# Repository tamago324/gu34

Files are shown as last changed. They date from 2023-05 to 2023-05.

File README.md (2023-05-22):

# gu34

horizon プラグインを使ってボトムプレートとトッププレートを生成した

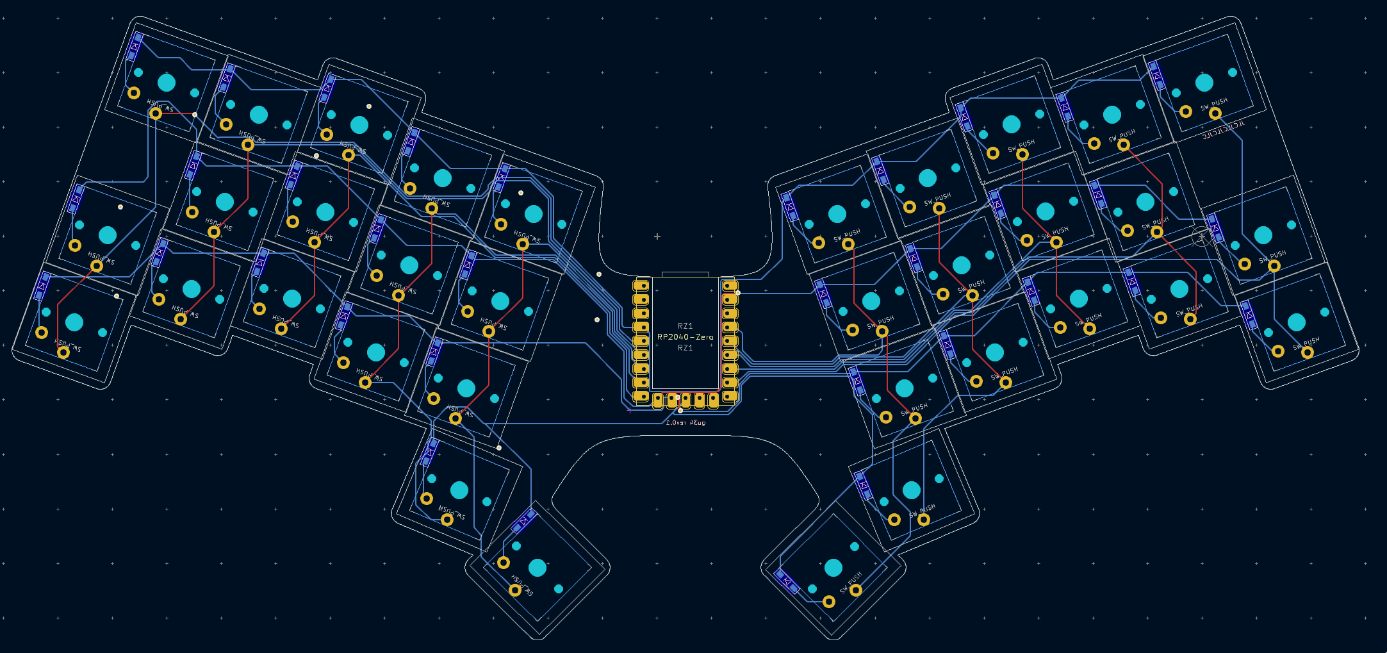
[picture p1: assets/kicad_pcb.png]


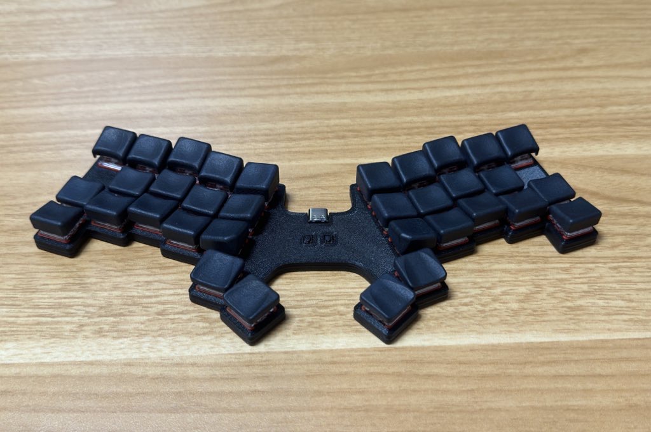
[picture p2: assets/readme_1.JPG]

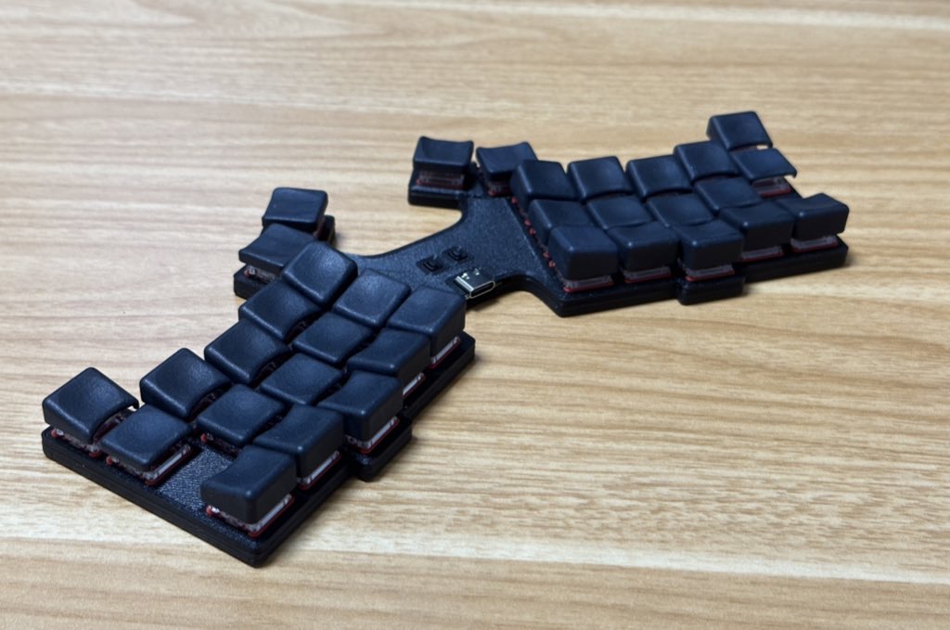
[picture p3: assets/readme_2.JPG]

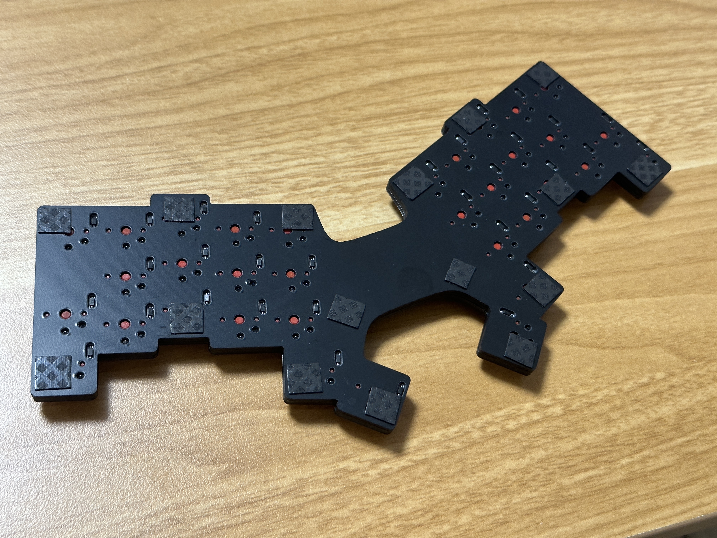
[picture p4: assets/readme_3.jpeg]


## LICENSE

<br />この 作品 は <a rel="license" href="http://creativecommons.org/licenses/by-nc/4.0/">クリエイティブ・コモンズ 表示 - 非営利 4.0 国際 ライセンス</a>の下に提供されています。

> 表示 — あなたは 適切なクレジットを表示し、ライセンスへのリンクを提供し、変更があったらその旨を示さなければなりません。これらは合理的であればどのような方法で行っても構いませんが、許諾者があなたやあなたの利用行為を支持していると示唆するような方法は除きます。
>
> 非営利 — あなたは営利目的でこの資料を利用してはなりません。

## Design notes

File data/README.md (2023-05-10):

# gu34

## 発注するためのデータの作り方

1. (horizon プラグイン)[https://github.com/skarrmann/horizon]を KiCAD に入れる
2. `revX` (`rev0.1` や `rev0.2` など) 内の `pcb/gu34.kicad_pcb` を開く
3. horizon プラグインを使って、発注するためのデータを作成する

## horizon プラグインの使い方

### もととなるKiCADのデータの作成方法

ボトムプレートとトッププレートを生成するためのデータはレイヤごとに作成されます

* `F.Adhesive` レイヤ：トッププレートの穴とEdge.Cuts
* `B.Adhesive` レイヤ：ボトムプレートの穴とEdge.Cuts

### horizon プラグインを使用して、ボトムプレートとトッププレートのデータを生成する

PCBエディタを開き、ツール > 外部プラグイン > Horizon Board Productor を実行する。

正しく実行できた場合、`data/` ディレクトリに `temp` と `gerbers` が生成される。

`temp` は KiCAD プロジェクトで、`gerbers` は JLCPCB (のみ？) に発注できるデータ。

`temp` を修正し、ガーバーファイルを生成して、発注することも可能

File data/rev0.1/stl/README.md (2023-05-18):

スイッチをはめるためのトッププレート

[Onshape](https://cad.onshape.com/documents/1d2e236c91f35d4d1f943853/w/506d06becb3141fa8ae01397/e/51f52be5848be2702f659e9b)

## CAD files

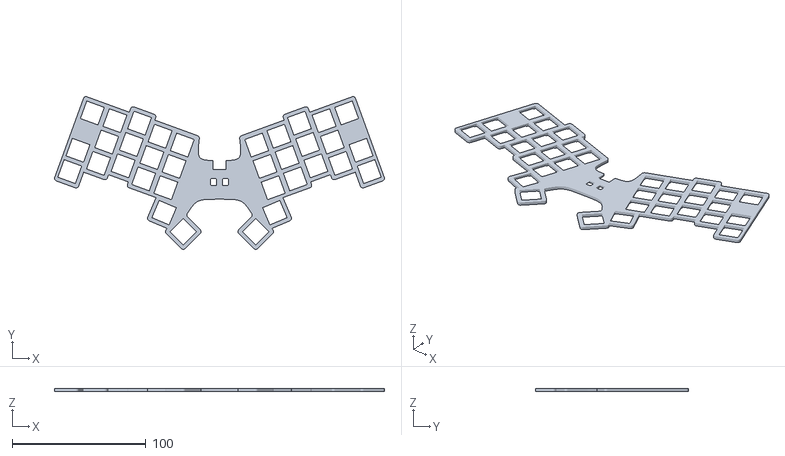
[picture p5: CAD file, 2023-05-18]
data/rev0.1/stl/top_plate.stl
247.2 x 114.5 x 2.20

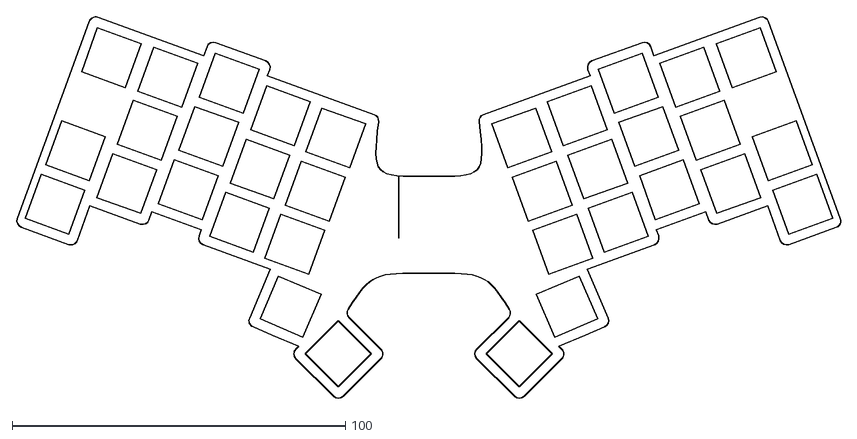
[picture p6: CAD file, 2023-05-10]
data/rev0.1/support.dxf
247.5 x 114.9

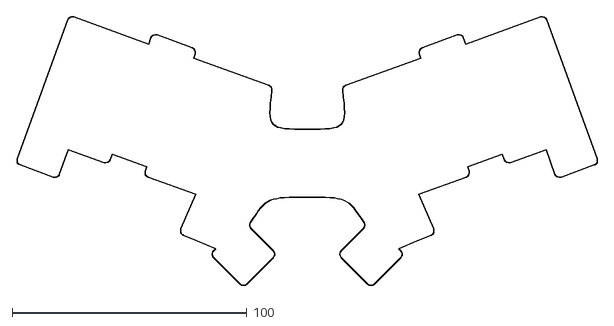
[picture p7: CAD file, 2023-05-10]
data/rev0.1/bottom_edge.dxf
247.5 x 114.9

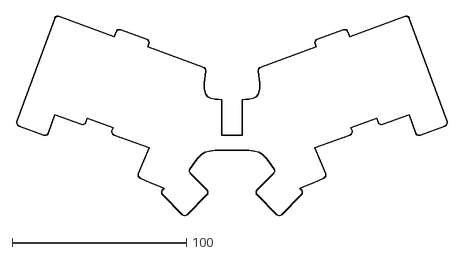
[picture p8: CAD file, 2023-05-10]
data/rev0.1/edge.dxf
247.7 x 114.7

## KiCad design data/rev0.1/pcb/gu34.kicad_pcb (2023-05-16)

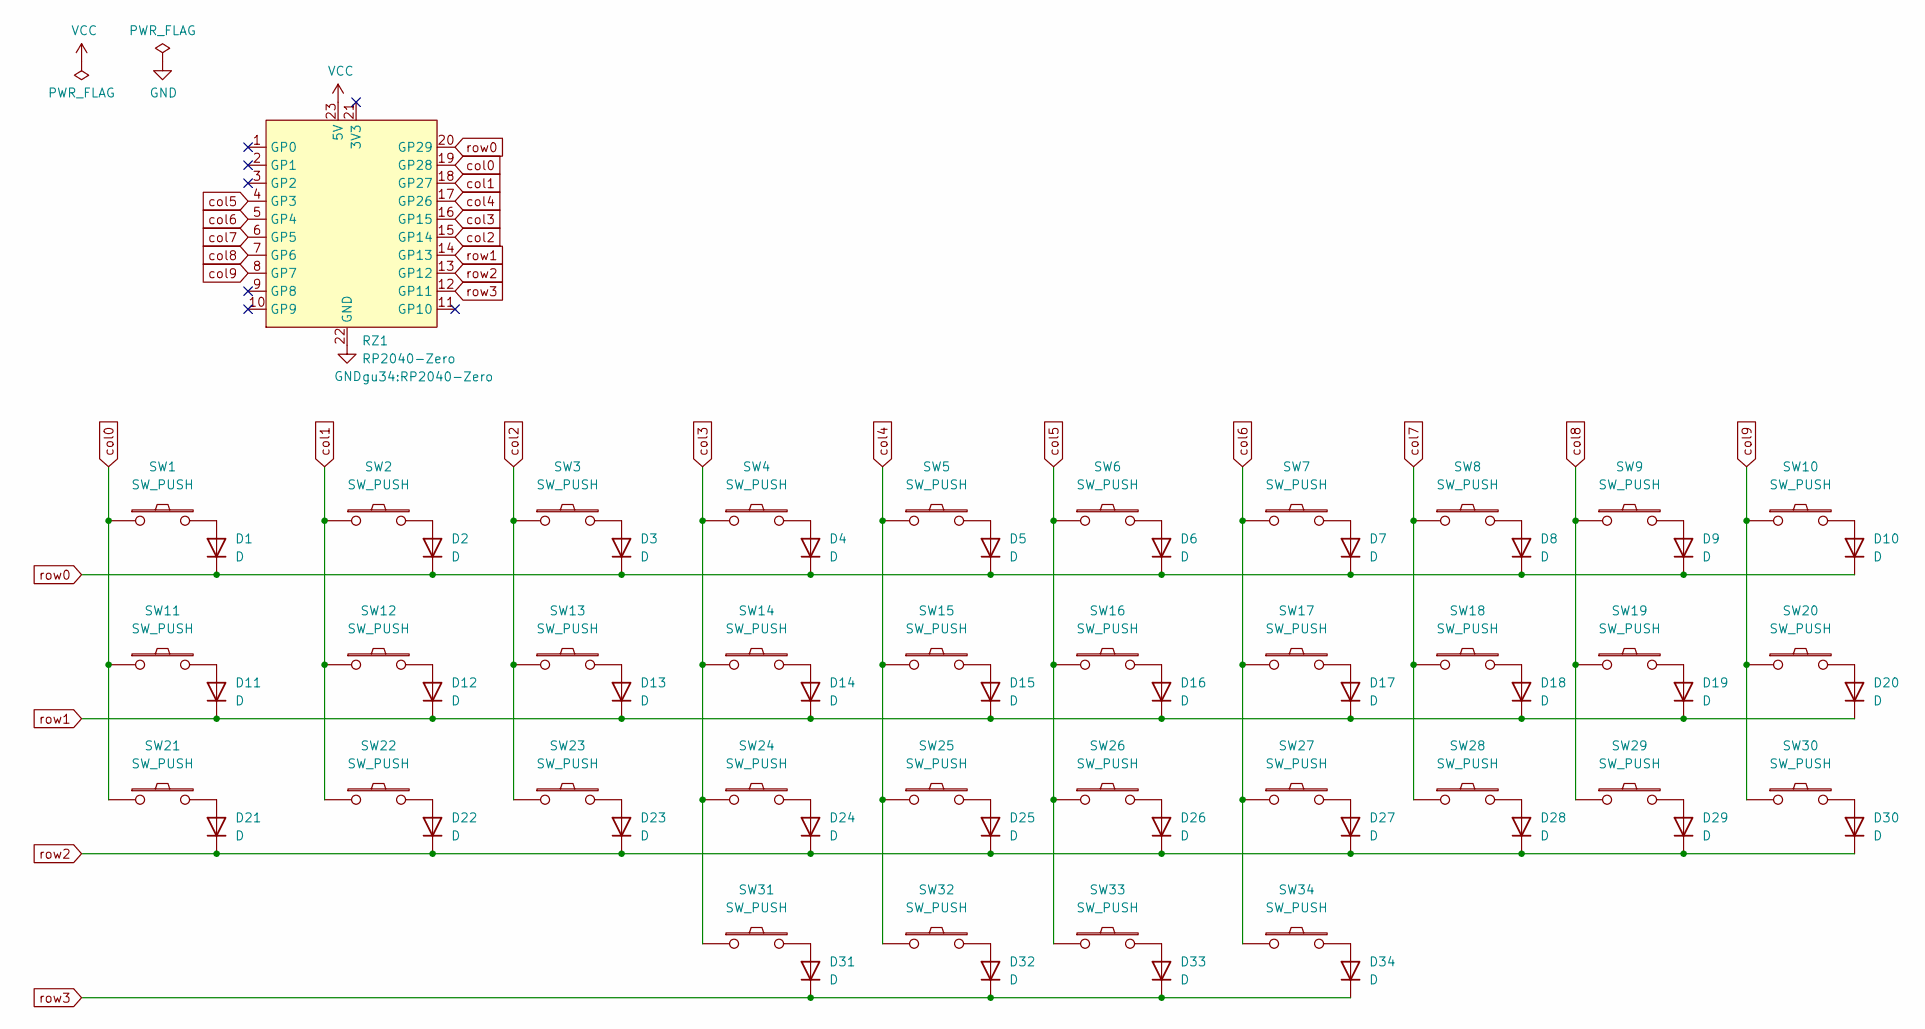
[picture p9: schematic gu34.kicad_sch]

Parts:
D1, D2, D3, D4, D5, D6, D7, D8, D9, D10, D11, D12, D13, D14, D15, D16, D17, D18, D19, D20, D21, D22, D23, D24, D25, D26, D27, D28, D29, D30, D31, D32, D33, D34: D; Diode_SMD
RZ1: RP2040-Zero
SW1, SW2, SW3, SW4, SW5, SW6, SW7, SW8, SW9, SW10, SW11, SW12, SW13, SW14, SW15, SW16, SW17, SW18, SW19, SW20, SW21, SW22, SW23, SW24, SW25, SW26, SW27, SW28, SW29, SW30, SW31, SW32, SW33, SW34: SW_PUSH; SW_Choc

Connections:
GND: RZ1.22 (GND)
unnamed: D1.2 (A), SW1.2
unnamed: D2.2 (A), SW2.2
unnamed: D3.2 (A), SW3.2
unnamed: D4.2 (A), SW4.2
unnamed: D5.2 (A), SW5.2
unnamed: D6.2 (A), SW6.2
unnamed: D7.2 (A), SW7.2
unnamed: D8.2 (A), SW8.2
unnamed: D9.2 (A), SW9.2
unnamed: D10.2 (A), SW10.2
unnamed: D11.2 (A), SW11.2
unnamed: D12.2 (A), SW12.2
unnamed: D13.2 (A), SW13.2
unnamed: D14.2 (A), SW14.2
unnamed: D15.2 (A), SW15.2
unnamed: D16.2 (A), SW16.2
unnamed: D17.2 (A), SW17.2
unnamed: D18.2 (A), SW18.2
unnamed: D19.2 (A), SW19.2
unnamed: D20.2 (A), SW20.2
unnamed: D21.2 (A), SW21.2
unnamed: D22.2 (A), SW22.2
unnamed: D23.2 (A), SW23.2
unnamed: D24.2 (A), SW24.2
unnamed: D25.2 (A), SW25.2
unnamed: D26.2 (A), SW26.2
unnamed: D27.2 (A), SW27.2
unnamed: D28.2 (A), SW28.2
unnamed: D29.2 (A), SW29.2
unnamed: D30.2 (A), SW30.2
unnamed: D31.2 (A), SW31.2
unnamed: D32.2 (A), SW32.2
unnamed: D33.2 (A), SW33.2
unnamed: D34.2 (A), SW34.2
VCC: RZ1.23 (5V)
col0: RZ1.19 (GP28), SW1.1, SW11.1, SW21.1
col1: RZ1.18 (GP27), SW2.1, SW12.1, SW22.1
col2: RZ1.15 (GP14), SW3.1, SW13.1, SW23.1
col3: RZ1.16 (GP15), SW4.1, SW14.1, SW24.1, SW31.1
col4: RZ1.17 (GP26), SW5.1, SW15.1, SW25.1, SW32.1
col5: RZ1.4 (GP3), SW6.1, SW16.1, SW26.1, SW33.1
col6: RZ1.5 (GP4), SW7.1, SW17.1, SW27.1, SW34.1
col7: RZ1.6 (GP5), SW8.1, SW18.1, SW28.1
col8: RZ1.7 (GP6), SW9.1, SW19.1, SW29.1
col9: RZ1.8 (GP7), SW10.1, SW20.1, SW30.1
row0: D1.1 (K), D2.1 (K), D3.1 (K), D4.1 (K), D5.1 (K), D6.1 (K), D7.1 (K), D8.1 (K), D9.1 (K), D10.1 (K), RZ1.20 (GP29)
row1: D11.1 (K), D12.1 (K), D13.1 (K), D14.1 (K), D15.1 (K), D16.1 (K), D17.1 (K), D18.1 (K), D19.1 (K), D20.1 (K), RZ1.14 (GP13)
row2: D21.1 (K), D22.1 (K), D23.1 (K), D24.1 (K), D25.1 (K), D26.1 (K), D27.1 (K), D28.1 (K), D29.1 (K), D30.1 (K), RZ1.13 (GP12)
row3: D31.1 (K), D32.1 (K), D33.1 (K), D34.1 (K), RZ1.12 (GP11)

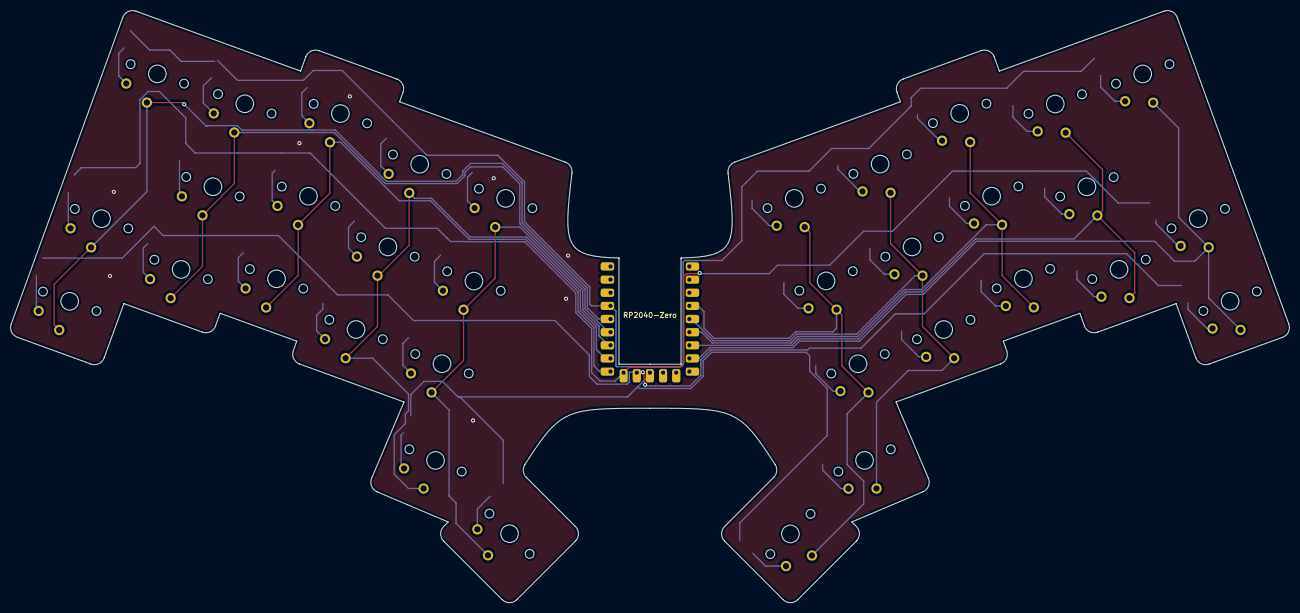
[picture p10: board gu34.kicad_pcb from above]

Board: 2 copper layers, 247.2 x 114.5 mm, 69 parts (0 on the bottom side), 48 nets.

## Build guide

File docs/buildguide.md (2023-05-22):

# gu34 ビルドガイド

gu34 のビルドガイドです。

## 必要なもの

| 名前 | 数量 | 備考 |
|---|---|---|
| Choc v1 キースイッチ | 34個 | - |
| キーキャップ | 34個 | - |
| USBケーブル | 1個  | - |
| RP2040 Zero | 1個  | - |
| 両面テープ | 1個  | - |
| ゴム足 or ゴムシート | 1個  | - |

## 組み立て順序の確認

1. ファームウェアの書き込み
2. プレートの側面をペンで塗る
3. ダイオードのはんだ付け
4. RP2040 をはんだ付けする
5. スイッチをはんだ付けする
6. ボトムプレートをつける
7. ゴム足をつける
7. キーキャップを取り付ける

## 組み立て

### 1. ファームウェアの書き込み

[QMK](https://github.com/tamago324/qmk_firmware/tree/tamago324/keyboards/tamago324/gu34) を使用して、ファームウェアを書き込みます。

### 2. プレートの側面をペンで塗る

PCB と ボトムプレートの側面をペンで塗るときれいに仕上げられます。

### 3. ダイオードのはんだ付け

PCBの裏にダイオードを34個はんだ付けします。
「PCBのシルクの線」と「ダイオードの線」が一致するようにはんだ付けします。
はんだごての温度は320℃くらいに設定し作業します。

片側に予備ハンダを行い、
ピンセットを使用して、はんだ付けを行い、
もう片方もはんだ付けします。

すべてのダイオードのはんだ付けが終わったら、すべてのダイオードが同じ向きになっていることを確認してください。

### 4. RP2040 をはんだ付けする

PCB の表に RP2040 Zero をはんだ付けする

表につけること。
表につけること。
表につけること。
表につけること。

裏につけると組み立てできなくなるので注意してください。

### 5. スイッチをはんだ付けする

トッププレートとPCBを合わせて、スイッチをはめ込み、はんだ付けする

トッププレートはオプションのため、なくてもOK

### 6. ボトムプレートをつける

両面テープでボトムプレートとPCBを貼り付ける

### 7. ゴム足を取り付ける

Griiip っていう薄いシートがおすすめ

### 8. キーキャップを取り付ける

キーキャップを取り付けます。

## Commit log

2023-05-10 typo 修正
2023-05-16 rp2040 zero のフットプリントとシンボルが正しくなかったため、修正した
    [gu34-B_Cu.gbr, gu34-B_Mask.gbr, gu34-B_Silks.gbr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]
2023-05-18 add top-plate
    [top_plate.stl]

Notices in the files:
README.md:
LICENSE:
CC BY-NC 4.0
